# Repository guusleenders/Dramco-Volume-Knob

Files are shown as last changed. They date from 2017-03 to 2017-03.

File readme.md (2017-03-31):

# Dramco-Volume-Knob

## Instructions Dramco Volume Knob

Download firmware (bootloader): https://github.com/micronucleus/micronucleus (in firmware/releases/t85_default.hex)
Program with ArduinoISP: 
"C:\Program Files (x86)\Arduino\hardware\tools\avr/bin/avrdude" -CC:"\Program Files (x86)\Arduino\hardware\tools\avr/etc/avrdude.conf" -v -pattiny85 -cstk500v1 -PCOM4 -b19200 -Uflash:w:t85_default.hex:i -U lfuse:w:0xe1:m -U hfuse:w:0x5d:m -U efuse:w:0xfe:m

Upload arduino sketch:
Install micronucleus drivers (in micronucleus driver installation folder)
Install digistum in Arduino IDE: add to board url http://digistump.com/package_digistump_index.json
Install "Digistump AVR boards" under the Tools... Board... Board Manager...
Choose Digispark default 16.5MHz.

You must insert / reinsert the ATTiny85's USB plug after the sketch has compiled and is ready to upload.

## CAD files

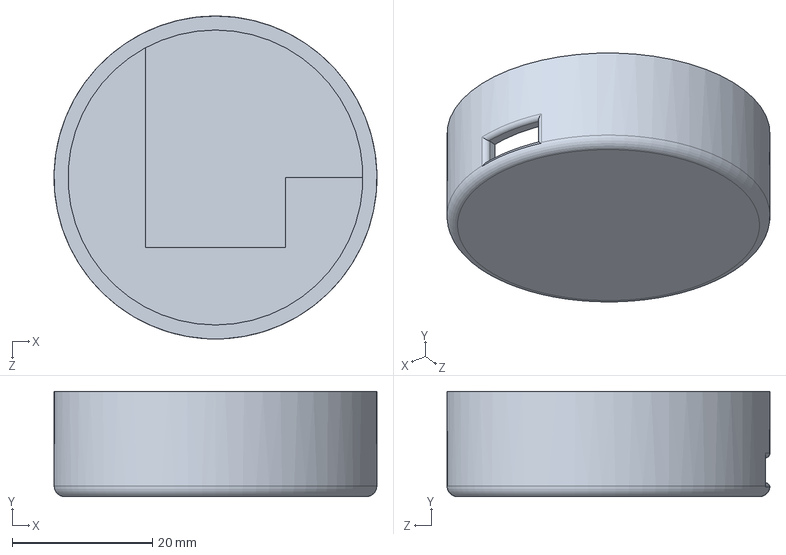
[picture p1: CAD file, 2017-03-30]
SolidWorks/Base.SLDPRT
46.0 x 15.0 x 46.0 mm

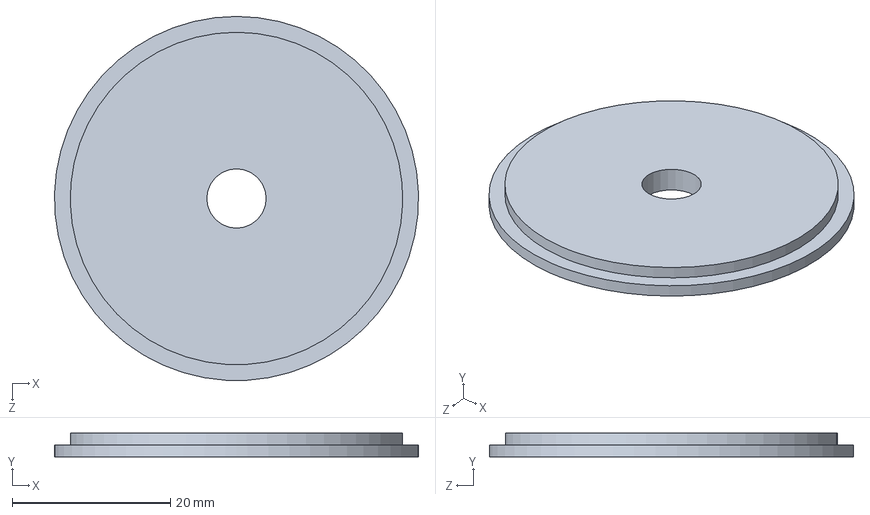
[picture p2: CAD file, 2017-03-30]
SolidWorks/Light guide.SLDPRT
46.0 x 3.00 x 46.0 mm

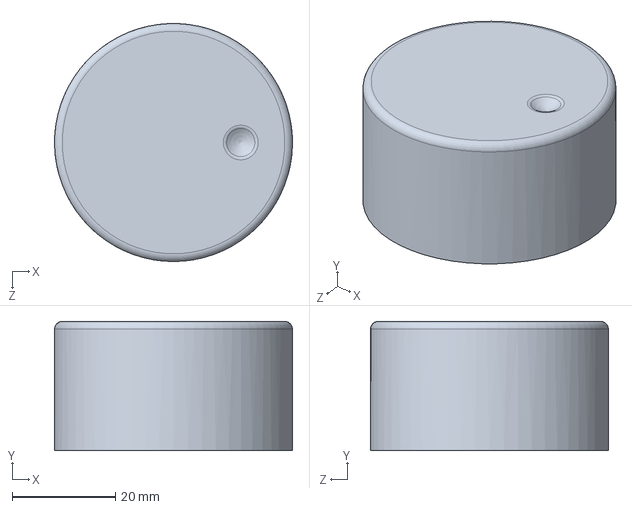
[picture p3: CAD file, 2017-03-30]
SolidWorks/Knob.SLDPRT
46.0 x 25.0 x 46.0 mm

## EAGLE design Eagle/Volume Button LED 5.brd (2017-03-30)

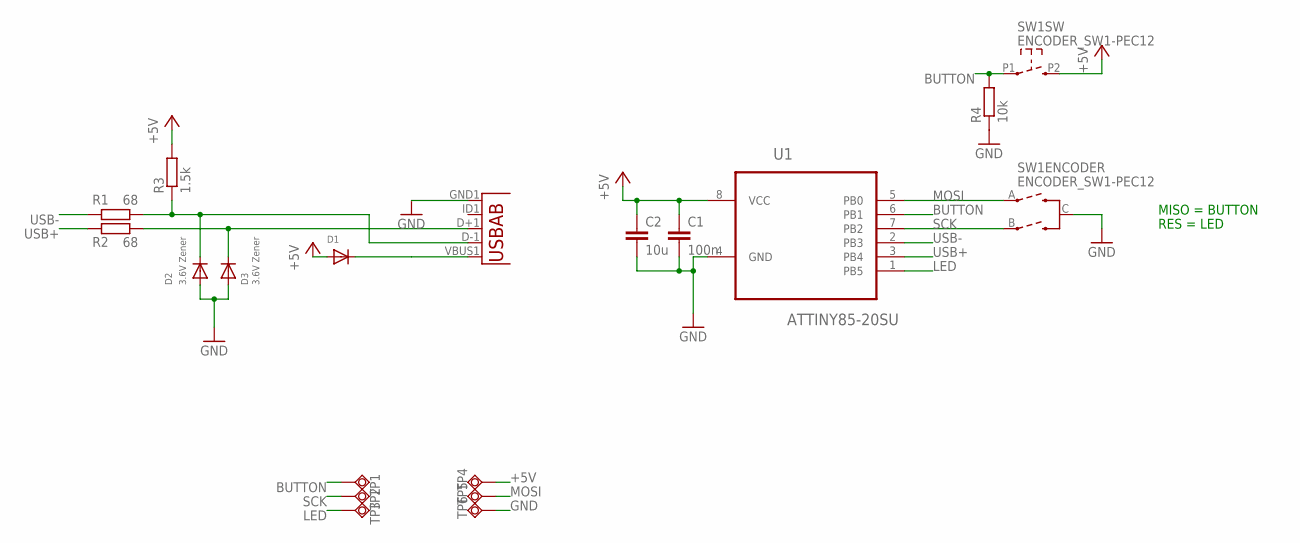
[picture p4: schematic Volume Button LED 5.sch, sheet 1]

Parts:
C1: 100n; C0805
C2: 10u; C0805
D1: DIODESOD-123; SOD-123
D2, D3: 3.6V Zener; SOD-323F
R1, R2: 68; R0603
R3: 1.5k; R0603
R4: 10k; R0805
SW1: ENCODER_SW1-PEC12; PEC12_INCREMENTAL_ENCODER
TP1, TP2, TP3, TP4, TP5, TP6: TPSQTP15R; TP15R
U1: ATTINY85-20SU; SOIC127P798X216-8N
U2: USB""; USB-MICRO-SMD

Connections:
+5V: C1.1, C2.1, D1.A, R3.2, SW1.P2 (2), TP4.TP, U1.8 (VCC); also elsewhere on the board
BUTTON: R4.2, SW1.P1 (1), TP1.TP, U1.6 (PB1)
GND: C1.2, C2.2, D2.A, D3.A, R4.1, SW1.C, TP6.TP, U1.4 (GND), U2.GND1 (GND); also elsewhere on the board
LED: TP3.TP, U1.1 (PB5); also elsewhere on the board
MOSI: SW1.A, TP5.TP, U1.5 (PB0)
unnamed: D1.C, U2.VBUS1 (VBUS)
unnamed: D2.C, R1.1, R3.1, U2.D-1 (D-)
unnamed: D3.C, R2.1, U2.D+1 (D+)
SCK: SW1.B, TP2.TP, U1.7 (PB2)
USB+: R2.2, U1.3 (PB4)
USB-: R1.2, U1.2 (PB3)

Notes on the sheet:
MISO = BUTTON
RES = LED

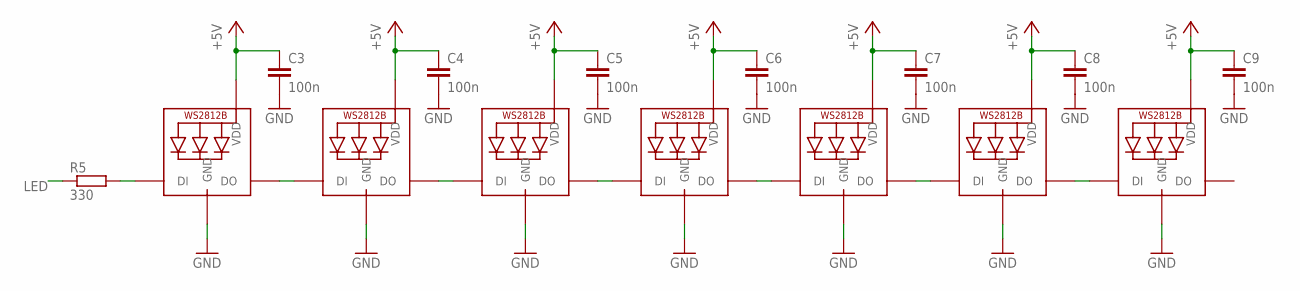
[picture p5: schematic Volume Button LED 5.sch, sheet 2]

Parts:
C3, C4, C5, C6, C7, C8, C9: 100n; C0805
LED1, LED2, LED3, LED4, LED5, LED6, LED7: WS2812B5050; WS2812B
R5: 330; R0805

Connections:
+5V: C3.1, C4.1, C5.1, C6.1, C7.1, C8.1, C9.1, LED1.1-VDD (VDD), LED2.1-VDD (VDD), LED3.1-VDD (VDD), LED4.1-VDD (VDD), LED5.1-VDD (VDD), LED6.1-VDD (VDD), LED7.1-VDD (VDD); also elsewhere on the board
GND: C3.2, C4.2, C5.2, C6.2, C7.2, C8.2, C9.2, LED1.3-GND (GND), LED2.3-GND (GND), LED3.3-GND (GND), LED4.3-GND (GND), LED5.3-GND (GND), LED6.3-GND (GND), LED7.3-GND (GND); also elsewhere on the board
LED: R5.1; also elsewhere on the board
unnamed: LED1.2-DOUT (DO), LED2.4-DIN (DI)
unnamed: LED1.4-DIN (DI), R5.2
unnamed: LED2.2-DOUT (DO), LED3.4-DIN (DI)
unnamed: LED3.2-DOUT (DO), LED4.4-DIN (DI)
unnamed: LED4.2-DOUT (DO), LED5.4-DIN (DI)
unnamed: LED5.2-DOUT (DO), LED6.4-DIN (DI)
unnamed: LED6.2-DOUT (DO), LED7.4-DIN (DI)

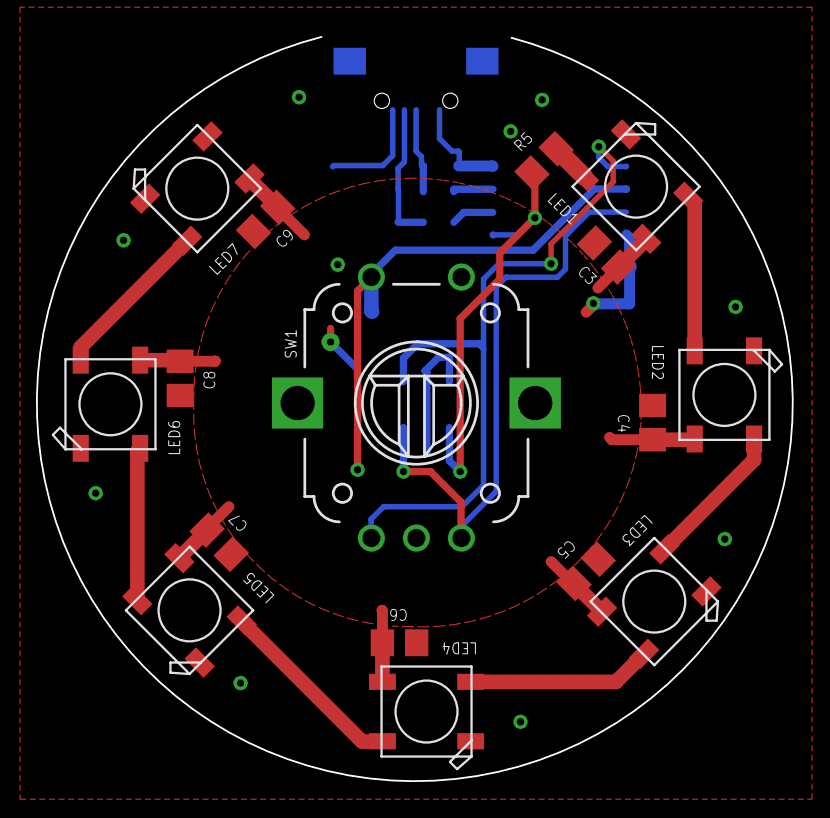
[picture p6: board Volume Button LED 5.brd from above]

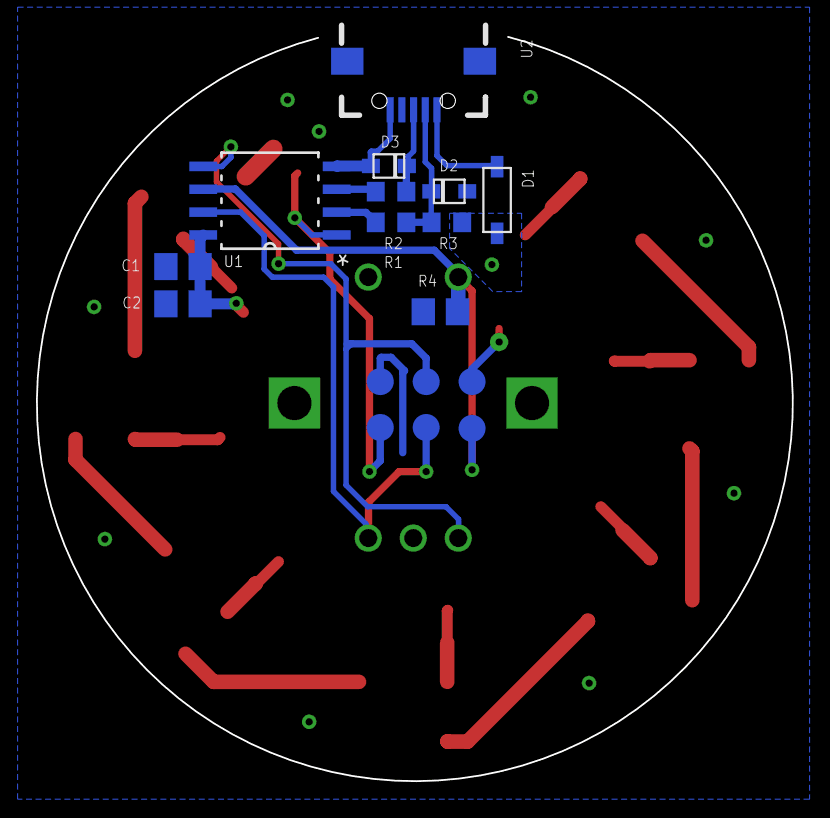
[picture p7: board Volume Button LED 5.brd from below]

Board: 2 copper layers, 42.0 x 41.3 mm, 33 parts (17 on the bottom side), 18 nets.

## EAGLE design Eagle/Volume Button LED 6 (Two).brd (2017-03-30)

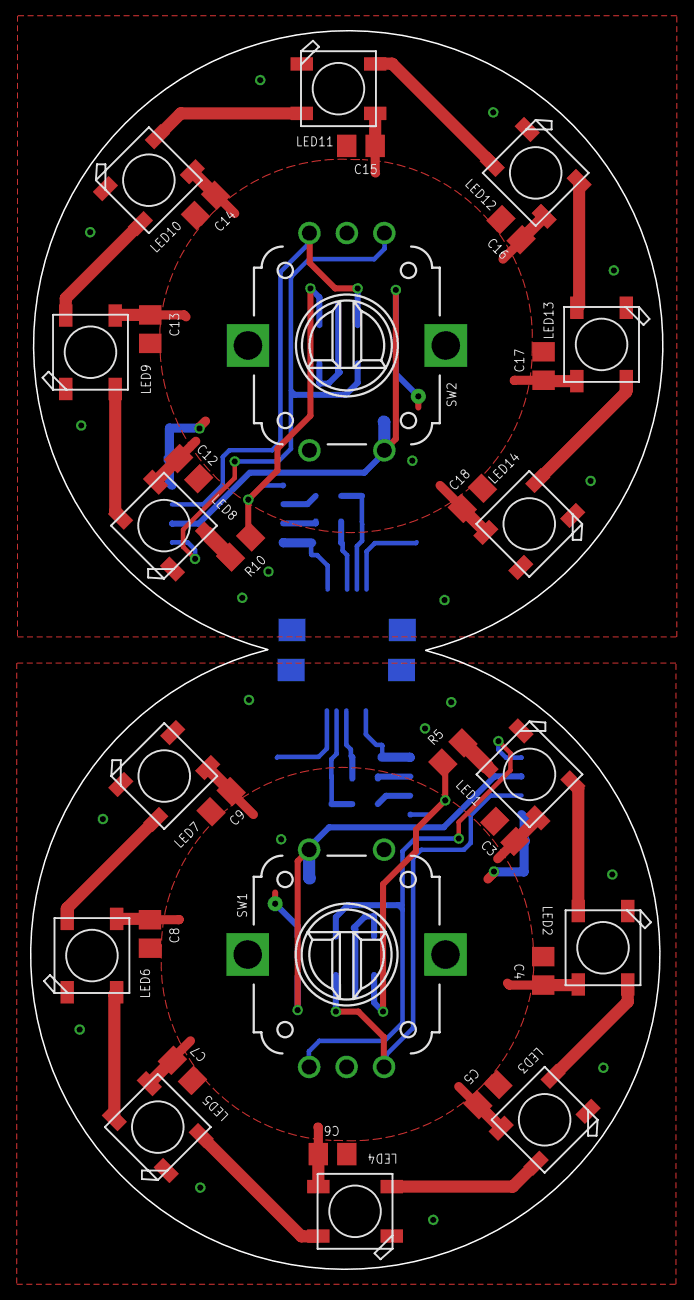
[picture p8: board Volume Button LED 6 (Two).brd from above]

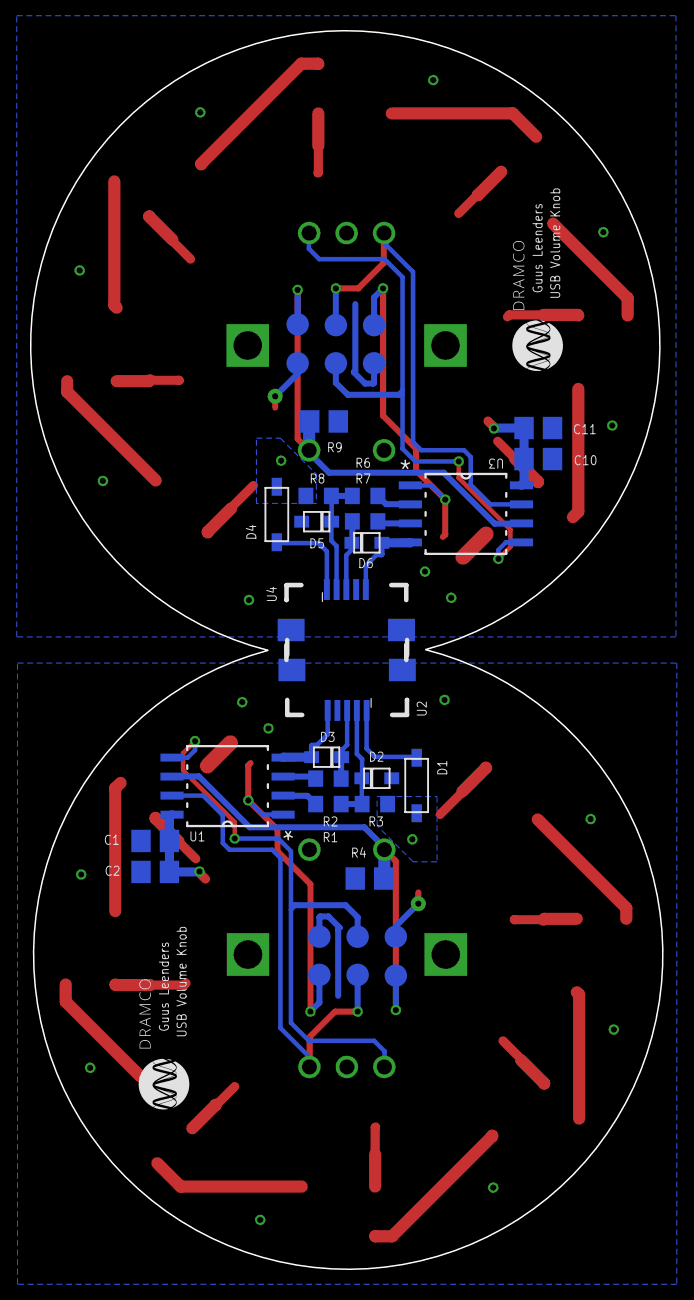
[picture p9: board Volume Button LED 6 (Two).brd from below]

Board: 2 copper layers, 42.2 x 82.7 mm, 66 parts (34 on the bottom side), 36 nets.

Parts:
C1, C3, C4, C5, C6, C7, C8, C9, C10, C12, C13, C14, C15, C16, C17, C18: 100n; C0805
C2, C11: 10u; C0805
D1, D4: SOD-123
D2, D3, D5, D6: 3.6V Zener; SOD-323F
LED1, LED2, LED3, LED4, LED5, LED6, LED7, LED8, LED9, LED10, LED11, LED12, LED13, LED14: WS2812B5050; WS2812B
R1, R2, R6, R7: 68; R0603
R3, R8: 1.5k; R0603
R4, R9: 10k; R0805
R5, R10: 330; R0805
SW1, SW2: ENCODER_SW1-PEC12; PEC12_INCREMENTAL_ENCODER
TP1, TP2, TP3, TP4, TP5, TP6, TP7, TP8, TP9, TP10, TP11, TP12: TPSQTP15R; TP15R
U1, U3: ATTINY85-20SU; SOIC127P798X216-8N
U2, U4: USB-MICRO-SMD

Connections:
+5V: C1.1, C2.1, C3.1, C4.1, C5.1, C6.1, C7.1, C8.1, C9.1, D1.A, LED1.1-VDD, LED2.1-VDD, LED3.1-VDD, LED4.1-VDD, LED5.1-VDD, LED6.1-VDD, LED7.1-VDD, R3.2, SW1.P2, TP4.TP, U1.8
+5V1: C10.1, C11.1, C12.1, C13.1, C14.1, C15.1, C16.1, C17.1, C18.1, D4.A, LED8.1-VDD, LED9.1-VDD, LED10.1-VDD, LED11.1-VDD, LED12.1-VDD, LED13.1-VDD, LED14.1-VDD, R8.2, SW2.P2, TP10.TP, U3.8
BUTTON: R4.2, SW1.P1, TP1.TP, U1.6
BUTTON1: R9.2, SW2.P1, TP7.TP, U3.6
GND: C1.2, C2.2, C3.2, C4.2, C5.2, C6.2, C7.2, C8.2, C9.2, D2.A, D3.A, LED1.3-GND, LED2.3-GND, LED3.3-GND, LED4.3-GND, LED5.3-GND, LED6.3-GND, LED7.3-GND, R4.1, SW1.C, TP6.TP, U1.4, U2.GND1
GND1: C10.2, C11.2, C12.2, C13.2, C14.2, C15.2, C16.2, C17.2, C18.2, D5.A, D6.A, LED8.3-GND, LED9.3-GND, LED10.3-GND, LED11.3-GND, LED12.3-GND, LED13.3-GND, LED14.3-GND, R9.1, SW2.C, TP12.TP, U3.4, U4.GND1
LED: R5.1, TP3.TP, U1.1
LED1: R10.1, TP9.TP, U3.1
MOSI: SW1.A, TP5.TP, U1.5
MOSI1: SW2.A, TP11.TP, U3.5
unnamed: LED1.2-DOUT, LED2.4-DIN
unnamed: D1.C, U2.VBUS1
unnamed: D2.C, R1.1, R3.1, U2.D-1
unnamed: D3.C, R2.1, U2.D+1
unnamed: LED1.4-DIN, R5.2
unnamed: D4.C, U4.VBUS1
unnamed: LED2.2-DOUT, LED3.4-DIN
unnamed: LED3.2-DOUT, LED4.4-DIN
unnamed: LED4.2-DOUT, LED5.4-DIN
unnamed: LED5.2-DOUT, LED6.4-DIN
unnamed: D5.C, R6.1, R8.1, U4.D-1
unnamed: LED6.2-DOUT, LED7.4-DIN
unnamed: D6.C, R7.1, U4.D+1
unnamed: LED8.2-DOUT, LED9.4-DIN
unnamed: LED9.2-DOUT, LED10.4-DIN
unnamed: LED10.2-DOUT, LED11.4-DIN
unnamed: LED11.2-DOUT, LED12.4-DIN
unnamed: LED12.2-DOUT, LED13.4-DIN
unnamed: LED13.2-DOUT, LED14.4-DIN
unnamed: LED8.4-DIN, R10.2
SCK: SW1.B, TP2.TP, U1.7
SCK1: SW2.B, TP8.TP, U3.7
USB+: R2.2, U1.3
USB+1: R7.2, U3.3
USB-: R1.2, U1.2
USB-1: R6.2, U3.2

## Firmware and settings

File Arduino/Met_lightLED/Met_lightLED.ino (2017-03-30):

#include "TrinketHidCombo.h"
#include <WS2812.h>

#define PIN_ENCODER_A 0
#define PIN_ENCODER_B 2
#define TRINKET_PINx  PINB
#define PIN_ENCODER_SWITCH 1
#define LED_PIN 5
#define NUMPIXELS 7

static uint8_t enc_prev_pos   = 0;
static uint8_t enc_flags      = 0;
static char    sw_was_pressed = 0;

WS2812 LED(NUMPIXELS);
cRGB value;

int currentPosition = 3;

const uint8_t PROGMEM gamma8[] = {
    0,  0,  0,  0,  0,  0,  0,  0,  0,  0,  0,  0,  0,  0,  0,  0,
    0,  0,  0,  0,  0,  0,  0,  0,  0,  0,  0,  0,  1,  1,  1,  1,
    1,  1,  1,  1,  1,  1,  1,  1,  1,  2,  2,  2,  2,  2,  2,  2,
    2,  3,  3,  3,  3,  3,  3,  3,  4,  4,  4,  4,  4,  5,  5,  5,
    5,  6,  6,  6,  6,  7,  7,  7,  7,  8,  8,  8,  9,  9,  9, 10,
   10, 10, 11, 11, 11, 12, 12, 13, 13, 13, 14, 14, 15, 15, 16, 16,
   17, 17, 18, 18, 19, 19, 20, 20, 21, 21, 22, 22, 23, 24, 24, 25,
   25, 26, 27, 27, 28, 29, 29, 30, 31, 32, 32, 33, 34, 35, 35, 36,
   37, 38, 39, 39, 40, 41, 42, 43, 44, 45, 46, 47, 48, 49, 50, 50,
   51, 52, 54, 55, 56, 57, 58, 59, 60, 61, 62, 63, 64, 66, 67, 68,
   69, 70, 72, 73, 74, 75, 77, 78, 79, 81, 82, 83, 85, 86, 87, 89,
   90, 92, 93, 95, 96, 98, 99,101,102,104,105,107,109,110,112,114,
  115,117,119,120,122,124,126,127,129,131,133,135,137,138,140,142,
  144,146,148,150,152,154,156,158,160,162,164,167,169,171,173,175,
  177,180,182,184,186,189,191,193,196,198,200,203,205,208,210,213,
  215,218,220,223,225,228,231,233,236,239,241,244,247,249,252,255 };
  
void setup()
{
  // set pins as input with internal pull-up resistors enabled
  pinMode(PIN_ENCODER_A, INPUT);
  pinMode(PIN_ENCODER_B, INPUT);
  digitalWrite(PIN_ENCODER_A, HIGH);
  digitalWrite(PIN_ENCODER_B, HIGH);

  pinMode(PIN_ENCODER_SWITCH, INPUT);
  // the switch is active-high, not active-low
  // since it shares the pin with Trinket's built-in LED
  // the LED acts as a pull-down resistor
  digitalWrite(PIN_ENCODER_SWITCH, LOW);

  TrinketHidCombo.begin(); // start the USB device engine and enumerate
  
  LED.setOutput(5);
  
  // get an initial reading on the encoder pins
  if (digitalRead(PIN_ENCODER_A) == LOW) {
    enc_prev_pos |= (1 << 0);
  }
  if (digitalRead(PIN_ENCODER_B) == LOW) {
    enc_prev_pos |= (1 << 1);
  }

  updateRing();

}

void updatePosition(int next){
  currentPosition = currentPosition + next;
  if(currentPosition < 0)
    currentPosition = currentPosition + 7;
  if(currentPosition > 6)
    currentPosition = currentPosition - 7;
  updateRing();
}

byte calcPosition(byte current, int next){
  int r = current + next;
  if(r < 0)
    r = r + 7;
  if(r > 6)
    r = r - 7;
  return r;
}

void updateRing(){
  value.b = pgm_read_byte(&gamma8[200]); value.g = pgm_read_byte(&gamma8[200]); value.r = pgm_read_byte(&gamma8[200]);
  LED.set_crgb_at(currentPosition, value);
  value.b = pgm_read_byte(&gamma8[85]); value.g = pgm_read_byte(&gamma8[85]); value.r = pgm_read_byte(&gamma8[85]);
  LED.set_crgb_at(calcPosition(currentPosition, -1), value); 
  LED.set_crgb_at(calcPosition(currentPosition, +1), value);
  value.b = pgm_read_byte(&gamma8[40]); value.g = pgm_read_byte(&gamma8[40]); value.r = pgm_read_byte(&gamma8[40]); 
  LED.set_crgb_at(calcPosition(currentPosition, -2), value);  
  LED.set_crgb_at(calcPosition(currentPosition, +2), value);
  value.b = 0; value.g = 0; value.r = 0; 
  LED.set_crgb_at(calcPosition(currentPosition, -3), value);
  LED.set_crgb_at(calcPosition(currentPosition, +3), value);
  LED.sync();
}

void loop(){

  
  int8_t enc_action = 0; // 1 or -1 if moved, sign is direction

  // note: for better performance, the code will now use
  // direct port access techniques
  // http://www.arduino.cc/en/Reference/PortManipulation
  uint8_t enc_cur_pos = 0;
  // read in the encoder state first
  if (bit_is_clear(TRINKET_PINx, PIN_ENCODER_A)) {
    enc_cur_pos |= (1 << 0);
  }
  if (bit_is_clear(TRINKET_PINx, PIN_ENCODER_B)) {
    enc_cur_pos |= (1 << 1);
  }

  // if any rotation at all
  if (enc_cur_pos != enc_prev_pos)
  {
    if (enc_prev_pos == 0x00)
    {
      // this is the first edge
      if (enc_cur_pos == 0x01) {
        enc_flags |= (1 << 0);
      }
      else if (enc_cur_pos == 0x02) {
        enc_flags |= (1 << 1);
      }
    }

    if (enc_cur_pos == 0x03)
    {
      // this is when the encoder is in the middle of a "step"
      enc_flags |= (1 << 4);
    }
    else if (enc_cur_pos == 0x00)
    {
      // this is the final edge
      if (enc_prev_pos == 0x02) {
        enc_flags |= (1 << 2);
      }
      else if (enc_prev_pos == 0x01) {
        enc_flags |= (1 << 3);
      }

      // check the first and last edge
      // or maybe one edge is missing, if missing then require the middle state
      // this will reject bounces and false movements
      if (bit_is_set(enc_flags, 0) && (bit_is_set(enc_flags, 2) || bit_is_set(enc_flags, 4))) {
        enc_action = 1;
      }
      else if (bit_is_set(enc_flags, 2) && (bit_is_set(enc_flags, 0) || bit_is_set(enc_flags, 4))) {
        enc_action = 1;
      }
      else if (bit_is_set(enc_flags, 1) && (bit_is_set(enc_flags, 3) || bit_is_set(enc_flags, 4))) {
        enc_action = -1;
      }
      else if (bit_is_set(enc_flags, 3) && (bit_is_set(enc_flags, 1) || bit_is_set(enc_flags, 4))) {
        enc_action = -1;
      }

      enc_flags = 0; // reset for next time
    }
  }

  enc_prev_pos = enc_cur_pos;

  if (enc_action > 0) {
    TrinketHidCombo.pressMultimediaKey(MMKEY_VOL_DOWN);
    updatePosition(-1);
  }
  else if (enc_action < 0) {
    TrinketHidCombo.pressMultimediaKey(MMKEY_VOL_UP);
    updatePosition(1);
  }

  // remember that the switch is active-high
  if (bit_is_set(TRINKET_PINx, PIN_ENCODER_SWITCH)) 
  {
    if (sw_was_pressed == 0) // only on initial press, so the keystroke is not repeated while the button is held down
    {
      TrinketHidCombo.pressMultimediaKey(MMKEY_MUTE);
      value.b = pgm_read_byte(&gamma8[100]); value.g = pgm_read_byte(&gamma8[100]); value.r = pgm_read_byte(&gamma8[100]);
      for(byte i = 0; i < 7; i++){
        LED.set_crgb_at(i, value);
      }
      LED.sync();
      delay(5); // debounce delay
    }
    sw_was_pressed = 1;
  }
  else
  {
    if (sw_was_pressed != 0) {
      value.b = 0; value.g = 0; value.r = 0;
      for(byte i = 0; i < 7; i++){
        LED.set_crgb_at(i, value);
      }
      updateRing();
      LED.sync();
      delay(5); // debounce delay
    }
    sw_was_pressed = 0;
  }

  TrinketHidCombo.poll(); // check if USB needs anything done
}

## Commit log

2017-03-30 First commit
    First commit
    [Base.SLDPRT, Knob.SLDPRT, Light guide.SLDPRT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]
2017-03-31 Added arduino folder for arduino IDE
